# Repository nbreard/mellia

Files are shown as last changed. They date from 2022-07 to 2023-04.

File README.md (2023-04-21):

# MD10 board

Environnement setup : 

Software :

 STM32CubeIDE : for compilation debugging and flashing 
		
 STM32CubeProgrammer: for deactivate write protection bit

Hardware : LoRaWAN gateway connected to LoRaWAN server (TTN)

# MELLIA - Kit Dadant 10

## Présentation

Le kit Mellia Dadant 10 est un ensemble de capteurs connectés permettant d’obtenir des informations essentielles relatives à l’exploitation d’une ruche dans l’objectif de suivre l’évolution de la colonie en réduisant le nombre d’interventions intrusives et les déplacement de l’apiculteur.

Ce kit s’adapte sur une ruche Dadant 10, le modèle le plus utilisé actuellement. Il comprend un dispositif de pesée électronique, un dispositif de mesure de température et humidité intérieure et extérieure, un capteur de pression atmosphérique ainsi qu’un module de communication sans fil. L’ensemble des acquisitions sont enregistrées dans une base de données, un tableau de bord permet le suivi de l’état de la ruche.

## Fonctionnalités

### Mesure poids de la ruche

On pèse la ruche à intervalle régulier pour faire remonter une donnée sur la masse à l’apiculteur. Cela permet d’obtenir un indice de l’état de santé de la colonie et d’envisager d’intervenir ou non sur la ruche (rajout de candi, miellée etc). 

### Température extérieure

Une captation de température dans l’environnement immédiat de la ruche renseigne l’apiculteur sur la météo du milieu dans lequel évolue la colonie d’abeille et donne la capacité d’anticiper une miellée par exemple.

### Température intérieure

La mesure de la température à l’intérieur de la ruche fournis une information sur l’état de santé du couvain. Pour se développer correctement sa température doit rester dans une plage de mesure de 18 à 35°C. Sortir de cette plage indique un danger pour la colonie. Des variations régulières de la température est un signe d’essaimage.

### Humidité extérieure

Utile au rafraîchissement de la ruche ou intervenant directement dans la probabilité de voir se développer des champignons, le taux d’humidité intervient directement dans la vie de la colonie et le mesurer peut se révéler être un élément clé pour comprendre l’activité de la ruche.

### Humidité intérieure

Cette donnée a une incidence sur l’état de santé du couvain, en effet si celui ci est trop humide les parois en deviennent fragiles. Le taux d’humidité est aussi un bon indicateur de la qualité du miel.

### Pression atmosphérique

En corrélation avec l’humidité et la température extérieure, la pression atmosphérique fournit à l’apiculteur une vision globale sur le milieu à proximité de la ruche et sur les éléments auxquels sont soumis les abeilles 

### [Tableau de bord](https://grafana.mellia.lab.open.studio/login "https://grafana.mellia.lab.open.studio/login")

Pour faciliter l’information et la prise de décision les données sont rassemblées dans un tableau de bords consultable en ligne.

## Notice

### Composants du kit

Pour les composants sur la carte se référer au document md10-board/hardware/wheather_board_v1/wheather_board_v1.csv

| composant | référence |
| --- | --- |
| jauge de contrainte | tedea 1242 |
| antenne | MOLEX  105262-0001 |
| boîtier | TAM 131007 ENCLOSURE |
| panneau solaire + batterie | |

### Montage

### Mise en œuvre

## Software 

**Prérequis** : 

Télécharger le logiciel STM32CubeIDE : <https://www.st.com/en/development-tools/stm32cubeide.html>

Télécharger le logiciel STM32CubeProgrammer : <https://www.st.com/en/development-tools/stm32cubeide.html>

Télécharger le code grâce à la commande suivante : 

Git clone <https://gitlab.openstudio-lab.com/mellia/mellia.git>

**Ouvrir le projet :** 

Ouvrir stm32CubeIde, sélectionner ~/md10-board/software/ruche\_soft comme workspace

Depuis STM32CubeIDE, cliquer sur File et « Open Project from file system »



Dans la fenêtre qui s’ouvre cliquer sur directory et sélectionner : ~/md10-board/software/ruche\_soft/STM32Cube\_FW\_WL\_V1.1.0/Projects/NUCLEO-WL55JC/Applications/LoRaWAN/LoRaWAN\_End\_Node/STM32CubeIDE

Les librairies des composants sont accessibles depuis Drivers. Le dossier Sensors contient les fonctions des différentes de mesures, poids, température etc.

Application contient le code de la machine à état qui fait tourner le programme mais aussi les drivers des périphériques de communication tel que le SPi l’i2c ou encore le protocole de communication LoRaWAN servant à faire remonter les données.

L’acquisition des mesures est faite au cours de la fonction SendTxData située dans lora\_app.c

**Flasher le programme :**

Connecter le debugger : 

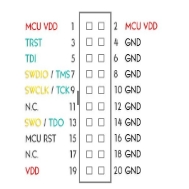
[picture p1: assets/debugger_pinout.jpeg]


Se connecter au microcontrolleur en utilise STM32Cubeprogramme et désactiver la protection en écriture : 

Pour lancer le debugger depuis stmcubeide appliquer cette configuration depuis Run -> debug configuration : 



Attention pour des raisons d’optimisation la sonde de debug et le mode low power est activé. Pour faire plus que flasher le code est debugger en mode pas à pas il faut se rendre dans sys\_conf.h et régler sur 1 les #define suivants : DEBUGGER\_ENABLED et LOW\_POWER\_DISABLE

**Procédure de calibration de la balance** 

On utilise les équations données par TI dans le document relatif à la bonne utilisation de la carte ADS1242 : 



On a besoin de 3 paramètres : 

- wfs  : la masse la plus proche possible de la pleine échelle
- Cfs  : la sortie de l’dc correspondant à wfs
- Czs : la sortie de l’adc lorsque la balance est à vide

À l’aide de ces trois données on peut en déduire l’équation 1 puis la 2 . On place un points d’arrêt dans le code après la mesure pour récupérer cfs et czs.

Les paramètres wzs et m sont à introduire en dur dans le code dans la fonction d’initialisation de l’ads1232 : void ADS1232Sensors\_Init(sensor\_t \*sensor\_data) 

Lors de l'assemblage d'une nouvelle balance, il est important de sélectionner les variables pour une jauge de 100kg ou de 250kg dans la fonction ADS1232Sensors_Init() contenu dans weight_sensor.c

#### Node-red

Node-red est un outil de développement basé sur les flux. Il sert ici à récupérer les données en provenance du broker MQTT fournit par TTN et à les enregistrer dans une base de donnée influxDB. Les ressources pour le déployer se situe dans le répertoir software

Pour se connecter au broker on commence par ajouter le module MQTT à l'interface node red en suivant ce tutoriel : 
https://www.thethingsnetwork.org/forum/t/mqtt-in-node-red-howto/39909

NB : nous utilisons Orange plutôt que TTN pour recevoir les données LoRa mais le principe est le même

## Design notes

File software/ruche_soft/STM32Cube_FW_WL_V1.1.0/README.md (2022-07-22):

# STM32CubeWL MCU Firmware Package



**STM32Cube** is an STMicroelectronics original initiative to ease developers' life by reducing efforts, time and cost.

**STM32Cube** covers the overall STM32 products portfolio. It includes a comprehensive embedded software platform (this repo), delivered for each series (such as the STM32CubeWL for the STM32WL series).
   * The CMSIS modules (core and device) corresponding to the ARM tm core implemented in this STM32 product
   * The STM32 HAL-LL drivers : an abstraction drivers layer, the API ensuring maximized portability across the STM32 portfolio 
   * The BSP Drivers of each evaluation or demonstration board provided by this STM32 series 
   * A consistent set of middlewares libraries such as RTOS, FatFS, LoRaWAN, Sigfox, Key Management Services ...
   * A full set of software projects (basic examples, applications or demonstrations) for each board provided by this STM32 series
   
The **STM32CubeWL MCU Package** projects are directly running on the STM32WL series boards. You can find in each Projects/*Board name* directories a set of software projects (Applications/Demonstration/Examples). 

## Boards available
  * STM32WL 
    * [NUCLEO-WL55JC](https://www.st.com/en/evaluation-tools/nucleo-wl55jc.html)

## Troubleshooting

**Caution** : The **Issues** requests are strictly limited to submit problems or suggestions related to the software delivered in this repo 

**For any question** related to the STM3WL product, the hardware performance, the hardware characteristics, the tools, the environment, you can submit a topic on the [ST Community/STM32 MCUs forum](https://community.st.com/s/group/0F90X000000AXsASAW/stm32-mcus)

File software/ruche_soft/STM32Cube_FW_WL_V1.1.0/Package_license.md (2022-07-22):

---
pagetitle: Package License Terms for <package RPN name>
lang: en
header-includes: <link rel="icon" type="image/x-icon" href="_htmresc/favicon.png" />
---

::: {.row}
::: {.col-sm-12 .col-lg-3}

<center>
# These are full license terms for

# <mark>STM32CubeWL</mark>

Copyright &copy; 2021 STMicroelectronics

All rights reserved
    
ST logo (https://www.st.com)
{.logo}
</center>
:::

::: {.col-sm-12 .col-lg-9}
::: {.collapse}
<input type="checkbox" id="collapse-section1" checked aria-hidden="true">
<label for="collapse-section1" aria-hidden="true">__SLA0048__</label>
<div>

SLA0048 Rev4/March 2018

## Software license agreement

### __SOFTWARE PACKAGE LICENSE AGREEMENT__

BY INSTALLING COPYING, DOWNLOADING, ACCESSING OR OTHERWISE USING THIS SOFTWARE PACKAGE OR ANY
PART THEREOF (AND THE RELATED DOCUMENTATION) FROM STMICROELECTRONICS INTERNATIONAL N.V, SWISS
BRANCH AND/OR ITS AFFILIATED COMPANIES (STMICROELECTRONICS), THE RECIPIENT, ON BEHALF OF HIMSELF
OR HERSELF, OR ON BEHALF OF ANY ENTITY BY WHICH SUCH RECIPIENT IS EMPLOYED AND/OR ENGAGED
AGREES TO BE BOUND BY THIS SOFTWARE PACKAGE LICENSE AGREEMENT.

Under STMicroelectronics’ intellectual property rights and subject to applicable licensing terms for any third-party software
incorporated in this software package and applicable Open Source Terms (as defined here below), the redistribution,
reproduction and use in source and binary forms of the software package or any part thereof, with or without modification, are
permitted provided that the following conditions are met:

1. Redistribution of source code (modified or not) must retain any copyright notice, this list of conditions and the following
disclaimer.

2. Redistributions in binary form, except as embedded into microcontroller or microprocessor device manufactured by or for
STMicroelectronics or a software update for such device, must reproduce the above copyright notice, this list of conditions
and the following disclaimer in the documentation and/or other materials provided with the distribution.

3. Neither the name of STMicroelectronics nor the names of other contributors to this software package may be used to
endorse or promote products derived from this software package or part thereof without specific written permission.

4. This software package or any part thereof, including modifications and/or derivative works of this software package, must
be used and execute solely and exclusively on or in combination with a microcontroller or a microprocessor devices
manufactured by or for STMicroelectronics.

5. No use, reproduction or redistribution of this software package partially or totally may be done in any manner that would
subject this software package to any Open Source Terms (as defined below).

6. Some portion of the software package may contain software subject to Open Source Terms (as defined below) applicable
for each such portion (“Open Source Software”), as further specified in the software package. Such Open Source Software
is supplied under the applicable Open Source Terms and is not subject to the terms and conditions of license hereunder.
“Open Source Terms” shall mean any open source license which requires as part of distribution of software that the source
code of such software is distributed therewith or otherwise made available, or open source license that substantially
complies with the Open Source definition specified at www.opensource.org and any other comparable open source license
such as for example GNU General Public License (GPL), Eclipse Public License (EPL), Apache Software License, BSD
license and MIT license.

7. This software package may also include third party software as expressly specified in the software package subject to
specific license terms from such third parties. Such third party software is supplied under such specific license terms and is
not subject to the terms and conditions of license hereunder. By installing copying, downloading, accessing or otherwise
using this software package, the recipient agrees to be bound by such license terms with regard to such third party
software.

8. STMicroelectronics has no obligation to provide any maintenance, support or updates for the software package.

9. The software package is and will remain the exclusive property of STMicroelectronics and its licensors. The recipient will
not take any action that jeopardizes STMicroelectronics and its licensors' proprietary rights or acquire any rights in the
software package, except the limited rights specified hereunder.

10. The recipient shall comply with all applicable laws and regulations affecting the use of the software package or any part
thereof including any applicable export control law or regulation.

11. Redistribution and use of this software package partially or any part thereof other than as permitted under this license is
void and will automatically terminate your rights under this license.

THIS SOFTWARE PACKAGE IS PROVIDED BY STMICROELECTRONICS AND CONTRIBUTORS "AS IS" AND ANY
EXPRESS, IMPLIED OR STATUTORY WARRANTIES, INCLUDING, BUT NOT LIMITED TO, THE IMPLIED WARRANTIES OF
MERCHANTABILITY, FITNESS FOR A PARTICULAR PURPOSE AND NON-INFRINGEMENT OF THIRD PARTY
INTELLECTUAL PROPERTY RIGHTS ARE DISCLAIMED TO THE FULLEST EXTENT PERMITTED BY LAW. IN NO EVENT
SHALL STMICROELECTRONICS OR CONTRIBUTORS BE LIABLE FOR ANY DIRECT, INDIRECT, INCIDENTAL, SPECIAL,
EXEMPLARY, OR CONSEQUENTIAL DAMAGES (INCLUDING, BUT NOT LIMITED TO, PROCUREMENT OF SUBSTITUTE
GOODS OR SERVICES; LOSS OF USE, DATA, OR PROFITS; OR BUSINESS INTERRUPTION) HOWEVER CAUSED AND
ON ANY THEORY OF LIABILITY, WHETHER IN CONTRACT, STRICT LIABILITY, OR TORT (INCLUDING NEGLIGENCE OR
OTHERWISE) ARISING IN ANY WAY OUT OF THE USE OF THIS SOFTWARE PACKAGE, EVEN IF ADVISED OF THE
POSSIBILITY OF SUCH DAMAGE.

EXCEPT AS EXPRESSLY PERMITTED HEREUNDER AND SUBJECT TO THE APPLICABLE LICENSING TERMS FOR ANY
THIRD-PARTY SOFTWARE INCORPORATED IN THE SOFTWARE PACKAGE AND OPEN SOURCE TERMS AS
APPLICABLE, NO LICENSE OR OTHER RIGHTS, WHETHER EXPRESS OR IMPLIED, ARE GRANTED UNDER ANY
PATENT OR OTHER INTELLECTUAL PROPERTY RIGHTS OF STMICROELECTRONICS OR ANY THIRD PARTY.

</div>
:::

::: {.collapse}
<input type="checkbox" id="collapse-section2" checked aria-hidden="true">
<label for="collapse-section2" aria-hidden="true">__ANNEX 1: LIST OF SOFTWARE COMPONENTS (AND ASSOCIATED LICENSES) IN THE SOFTWARE PACKAGE__</label>
<div>
Component                       Copyright                           License
---------                       ---------                           -------
CMSIS                           ARM Limited                         [Apache-2.0](https://opensource.org/licenses/Apache-2.0)
CMSIS Device                    ARM Limited - STMicroelectronics    [Apache-2.0](https://opensource.org/licenses/Apache-2.0)
STM32WL HAL                     STMicroelectronics                  [BSD-3-Clause](https://opensource.org/licenses/BSD-3-Clause)
BSP NUCLEO-WL55JC               STMicroelectronics                  [BSD-3-Clause](https://opensource.org/licenses/BSD-3-Clause)
FreeRTOS kernel                 Amazon.com, Inc. or its affiliates  [MIT](https://opensource.org/licenses/MIT) 
FatFS                           ChaN - STMicroelectronics           [BSD-3-Clause](https://opensource.org/licenses/BSD-3-Clause)
SubGHz_Phy                      Semtech - STMicroelectronics        [BSD-3-Clause](https://opensource.org/licenses/BSD-3-Clause)
LoRaWAN                         Semtech - STMicroelectronics        [BSD-3-Clause](https://opensource.org/licenses/BSD-3-Clause)
Sigfox                          Sigfox - STMicroelectronics         Proprietary and See ANNEX 2
mbed-crypto                     ARM Limited (or its affiliates)     [Apache-2.0](https://opensource.org/licenses/Apache-2.0)
STM32_Key_Management_Services   STMicroelectronics                  Proprietary
STM32_Secure_Engine             STMicroelectronics                  Proprietary
STM32 Projects                  STMicroelectronics                  Proprietary ([BSD-3-Clause](https://opensource.org/licenses/BSD-3-Clause) for basic Examples)
STM32 Utilities                 STMicroelectronics                  [BSD-3-Clause](https://opensource.org/licenses/BSD-3-Clause)

</div>
:::

::: {.collapse}
<input type="checkbox" id="collapse-section3" checked aria-hidden="true">
<label for="collapse-section3" aria-hidden="true">__ANNEX 2: SIGFOX Specific Terms__</label>
<div>

By downloading, or attempting to download, the SIGFOX protocol library "SFX_LIB_V2.10.0_SE_FDL_MON.a" and/or 
"SFX_ADDON_RFP_V0.8.0_SE_FDL_MON_ASYNC.a" , you are hereby informed and you acknowledge and agree that any use of 
the licensed materials is subject to all terms and conditions required by SIGFOX and listed below:
• You shall 
  o respect the Partner Certification Process, described in the SIGFOX developer platform at  
    http://build.SIGFOX.com to embed applicable authentication keys; 
  o be in compliance with all applicable laws, regulations (including any applicable 
    export control law or regulation) and industry standards in connection with the manufacture, sale 
    and/or distribution of certified products;
• You shall not:
 o modify or create without SIGFOX written prior agreement any derivative work of any part of the 
   SIGFOX protocol library 
 o market, sell, license, distribute, publish, display, reproduce, rent, lease, loan, assign or otherwise 
   transfer to a third party the SIGFOX protocol library or any copy thereof, in whole or in part; 
 o install or otherwise incorporate the SIGFOX protocol library into a product except as set 
   forth in and in accordance with this document; 
 o use the SIGFOX protocol library in any way that would not be in compliance with applicable laws; 
 o except to the extent permitted by law, permit the disassembly, decompilation or reverse engineering
   of the SIGFOX protocol library or otherwise attempt to gain access to the source code to the SIGFOX 
   protocol library (or the underlying ideas, algorithms, structure or organization of the object code 
   in the SIGFOX protocol library)
 o incorporate any open source software into any product, including with respect to certified products 
   sold or distributed, that creates or purports to create any obligation to disclose to a third party 
   any source code relating to the SIGFOX protocol library or grants or purports to grant to any third 
   party any intellectual property of SIGFOX; 
 o develop, sell or distribute any product that undermines SIGFOX network security and integrity and/or 
   introduces in any SIGFOX network any viruses, worms, Trojan horses or similar harmful or malicious 
   code, or otherwise harms any SIGFOX network; 
 o remove or attempt to remove any SIGFOX authentication keys,
 o incorporate the SIGFOX protocol library in any product for connection on another network than SIGFOX 
   network. You shall inform any of your third party that such infringement to the obligations below 
   would cause significant harm to SIGFOX.

You shall have no rights to any source code for the SIGFOX protocol library. You agree that only SIGFOX 
shall have the right to maintain, enhance or otherwise modify the SIGFOX protocol library. 

</div>
:::

:::
:::

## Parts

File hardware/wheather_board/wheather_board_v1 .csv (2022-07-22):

Id | Designator | Package | Quantity | Designation | tol���rance | tension nominale | ref fabricant
1 | C7,C3 | C_0805_2012Metric_Pad1.18x1.45mm_HandSolder | 2 | 2.2uF | 10.00% | 25V | 08053C225KAT2A
2 | ,REF**,REF**, | MountingHole_3.7mm_Pad_Via | 4 | MountingHole_3.7mm_Pad_Via | x | x | x
3 | J2 | PinSocket_1x02_P2.54mm_Vertical | 1 | Conn_01x02_Male | x | x | 826629-2
4 | J1 | PinSocket_1x02_P2.54mm_Vertical | 1 | Conn_01x02_Female | x | x | 282834-2
5 | SW1 | SW_SPST_PTS645 | 1 | SW_MEC_5G | x |  | KSEK43J LFS
6 | C25 | CP_EIA-7343-31_Kemet-D_Pad2.25x2.55mm_HandSolder | 1 | 100uF | 20.00% | 10V | T491D107M010AT
7 | C22 | Capacitor_Tantalum_SMD:CP_EIA-3216-18_Kemet-A | 1 | 0.1uF | 10.00% | 35V | T491A104K035AT
8 | R14 | R_0805_2012Metric_Pad1.20x1.40mm_HandSolder | 1 | 10k | 0.10% | 50V | ERA6AEB103V
9 | U4 | LD39050PUR | 1 | LD39050PU33R | 2.00% | 3.3V | LD39050PU33R
10 | U5 | SOIC-8_3.9x4.9mm_P1.27mm | 1 | REF5050AD | 20ppm | 5V | REF5050AID
11 | U2 | Bosch_LGA-8_3x3mm_P0.8mm_ClockwisePinNumbering | 1 | BME680 | x
12 | U1 | SOT-223-3_TabPin2 | 1 | LD1117S50TR_SOT223 | 2.00%
13 | R13 | R_0805_2012Metric_Pad1.20x1.40mm_HandSolder | 1 | DNP | x | x | x
14 | R10,R9 | R_0805_2012Metric_Pad1.20x1.40mm_HandSolder | 3 | 0 | 5.00% | 150V
15 | R12,R11 | R_0805_2012Metric_Pad1.20x1.40mm_HandSolder | 2 | 100 | 0.10% | 150V | MCTC0525B1000T5G
16 | R8 | R_0805_2012Metric_Pad1.20x1.40mm_HandSolder | 1 | 1 | 1.00% | 150V | RC0805FR-071RL
17 | R7,R6,R5 | R_0805_2012Metric_Pad1.20x1.40mm_HandSolder | 3 | 22 | 1.00% | 150V | MCWR08X22R0FTL
18 | R4,R3,R2,R1 | R_0805_2012Metric_Pad1.20x1.40mm_HandSolder | 4 | 22 | 1.00% | 150V | MCWR08X22R0FTL
19 | L1 | L_0805_2012Metric_Pad1.15x1.40mm_HandSolder | 1 | dnp | x | x | x
20 | J9 | U.FL_Hirose_U.FL-R-SMT-1_Vertical | 1 | Conn_Coaxial | x |  | U.FL-R-SMT(01)
21 | J8 | PinHeader_1x04_P2.54mm_Vertical | 1 | Conn_01x04_Male | x |  | 282834-4
22 | J7 | PinHeader_1x06_P2.54mm_Vertical | 1 | Conn_01x06_Female | x |  | 1725698
23 | J6,J10 | PinHeader_1x05_P2.54mm_Vertical | 2 | Conn_01x05_Female | x |  | 282834-5
24 | D1 | D_SMB-SMC_Universal_Handsoldering | 1 | D | x |  | MRS1504T3G
25 | C29,C27 | C_0805_2012Metric_Pad1.18x1.45mm_HandSolder | 2 | dnp | x
26 | C28,C11,C9,C6,C4 | C_0805_2012Metric_Pad1.18x1.45mm_HandSolder | 5 | 100nF | 20.00% | 50V
27 | C26 | C_0805_2012Metric_Pad1.18x1.45mm_HandSolder | 1 | 4.7uF | -400 | 16V | C0805C475J4RACAUTO
28 | C24,C21,C10,C8 | C_0805_2012Metric_Pad1.18x1.45mm_HandSolder | 4 | 1uF | 10.00% | 16V | MC0805B105K160CT
29 | C23 | C_0805_2012Metric_Pad1.18x1.45mm_HandSolder | 1 | 1uF | 10.00% | 16V | MC0805B105K160CT
30 | C20,C19,C18,C17 | NFM21PC105B1C3D | 4 | C_Feedthrough | 20.00% | 16V | NFM21PC105B1C3D
31 | C16,C15,C13,C12 | C_0805_2012Metric_Pad1.18x1.45mm_HandSolder | 4 | 100pF | 5.00% | 50V | CC0805JRNPO9BN101
32 | C14 | C_0805_2012Metric_Pad1.18x1.45mm_HandSolder | 1 | 10uF | 20.00% | 10V | C0805X106M8RACTU
33 | C5 | CP_EIA-3216-18_Kemet-A_Pad1.58x1.35mm_HandSolder | 1 | 10uF | 10.00% | 16V | T491A106K016AT
34 | C2 | C_1210_3225Metric_Pad1.33x2.70mm_HandSolder | 1 | 0.1uF | 10.00% | 50V
35 | C1 | CP_EIA-3528-21_Kemet-B_Pad1.50x2.35mm_HandSolder | 1 | 10uF | 10.00% | 10V | T494B106M010AT
36 | J5 | PinHeader_1x06_P2.54mm_Vertical | 1 | Conn_01x06_Male | x |  | 9731113
37 | J4 | PinHeader_1x03_P2.54mm_Vertical | 1 | Conn_01x03_Male | x |  | 9731083
38 | U3 | ADS1232IPW | 1 | PW0024A_N | x |  | ADS1232IPW
39 | U6 | LoRa-E5 | 1 | LoRa-E5 | x |  | 317990687
40 |  | CRE1S0505SC | 1 | CRE1S0505SC | x |  | CRE1S0505SC
41 | G*** | logo_mellia | 1 | MELLIA | x |  | x

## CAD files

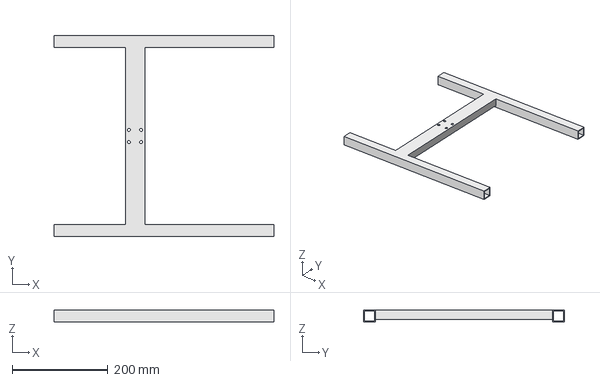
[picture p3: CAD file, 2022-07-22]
mechanic/weight_scale_frame.FCStd
460.0 x 420.0 x 25.0 mm

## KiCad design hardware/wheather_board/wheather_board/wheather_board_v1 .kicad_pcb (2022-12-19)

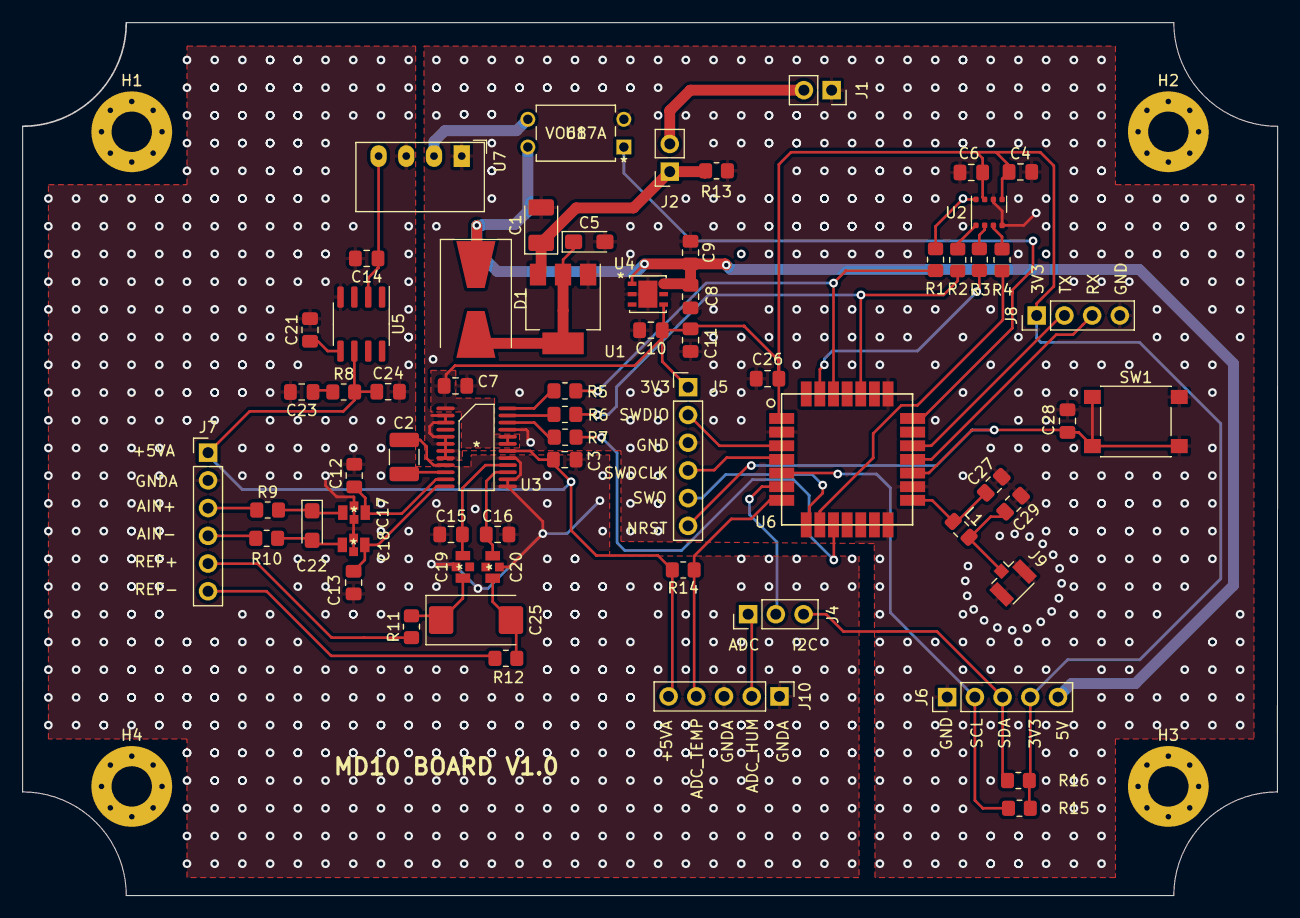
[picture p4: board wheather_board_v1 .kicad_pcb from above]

Board: 2 copper layers, 115.0 x 80.0 mm, 69 parts (0 on the bottom side), 53 nets.

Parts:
C1: 10uF; CP_EIA-3528-21_Kemet-B_Pad1.50x2.35mm_HandSolder
C2: 0.1uF; C_1210_3225Metric_Pad1.33x2.70mm_HandSolder
C3, C7: 2.2uF; C_0805_2012Metric_Pad1.18x1.45mm_HandSolder
C4, C6, C9, C11, C28: 100nF; C_0805_2012Metric_Pad1.18x1.45mm_HandSolder
C5: 10uF; CP_EIA-3216-18_Kemet-A_Pad1.58x1.35mm_HandSolder
C8, C10, C21, C24: 1uF; C_0805_2012Metric_Pad1.18x1.45mm_HandSolder
C12, C13, C15, C16: 100pF; C_0805_2012Metric_Pad1.18x1.45mm_HandSolder
C14: 1uF to 10 uF; C_0805_2012Metric_Pad1.18x1.45mm_HandSolder
C17, C18, C19, C20: C_Feedthrough; NFM21PC105B1C3D
C22: 0.1uF; CP_EIA-3216-18_Kemet-A
C23: 1uF to 50uF; C_0805_2012Metric_Pad1.18x1.45mm_HandSolder
C25: 100uF; CP_EIA-7343-31_Kemet-D_Pad2.25x2.55mm_HandSolder
C26: 4.7uF; C_0805_2012Metric_Pad1.18x1.45mm_HandSolder
C27, C29: dnp; C_0805_2012Metric_Pad1.18x1.45mm_HandSolder
D1: D; D_SMB-SMC_Universal_Handsoldering
H1, H2, H3, H4: MountingHole; MountingHole_3.7mm_Pad_Via
J1: Conn_01x02_Female; PinSocket_1x02_P2.54mm_Vertical
J2: Conn_01x02_Male; PinSocket_1x02_P2.54mm_Vertical
J4: Conn_01x03_Male; PinHeader_1x03_P2.54mm_Vertical
J5: Conn_01x06_Male; PinHeader_1x06_P2.54mm_Vertical
J6, J10: Conn_01x05_Female; PinHeader_1x05_P2.54mm_Vertical
J7: Conn_01x06_Female; PinHeader_1x06_P2.54mm_Vertical
J8: Conn_01x04_Male; PinHeader_1x04_P2.54mm_Vertical
J9: Conn_Coaxial; U.FL_Hirose_U.FL-R-SMT-1_Vertical
L1: dnp; L_0805_2012Metric_Pad1.15x1.40mm_HandSolder
R1, R2, R3, R4, R15, R16: R; R_0805_2012Metric_Pad1.20x1.40mm_HandSolder
R5, R6, R7: 22; R_0805_2012Metric_Pad1.20x1.40mm_HandSolder
R8: 1; R_0805_2012Metric_Pad1.20x1.40mm_HandSolder
R9, R10, R13: 0; R_0805_2012Metric_Pad1.20x1.40mm_HandSolder
R11, R12: 100; R_0805_2012Metric_Pad1.20x1.40mm_HandSolder
R14: 10k; R_0805_2012Metric_Pad1.20x1.40mm_HandSolder
SW1: SW_MEC_5G; SW_SPST_PTS645
U1: LD1117S50TR_SOT223; SOT-223-3_TabPin2
U2: BME680; Bosch_LGA-8_3x3mm_P0.8mm_ClockwisePinNumbering
U3: ADS1232IPW
U4: LD39050PUR
U5: REF5050AD; SOIC-8_3.9x4.9mm_P1.27mm
U6: LoRa-E5
U7: CRE1S0505SC; Converter_DCDC_muRata_CRE1xxxxxxSC_THT
U8: VO617A

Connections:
+3.3V: J6.4, R15.2, R16.2
+3V3: C4.1, C6.1, C7.2, C10.1, C11.1, C26.1, J5.1, J8.1, U2.6 (VDDIO), U2.8 (VDD), U3.1 (DVDD), U3.19 (GAIN0), U3.20 (GAIN1), U4.4 (VOUT), U6.1 (VCC)
+5V: C8.2, C9.2, D1.1 (K), J6.5, U4.1 (EN), U4.6 (VIN), U8.4 (C)
+5VA: C3.1, C24.1, J7.1, J10.5, R8.2, R14.2, U3.18 (AVDD), U5.6 (Vout)
/ADC_HUM: J4.1, J10.2
/ADC_TEMP: J10.4, R14.1, U6.7 (PB4)
/ADS_NSS: R7.1, U6.10 (PB6)
/AIN+: J7.3, R9.1
/AIN-: J7.4, R10.1
/AINN1: C13.1, C18.3, U3.12 (AINN1)
/AINP1: C12.2, C17.1, U3.11 (AINP1)
/BME_NSS: R4.1, U6.9 (PB7)
/EN_VDDA: U6.21 (PA9), U8.1 (A)
/I2C_SCL: J6.2, R15.1, U6.5 (PB15)
/I2C_SDA: J4.3, J6.3, R16.1
/NRST: C28.2, J5.6, SW1.1 (A), SW1.2 (A), U6.17 (RST)
/REFN: C16.1, C20.3, U3.15 (REFN)
/REFP: C15.2, C19.1, U3.16 (REFP)
/SPI_MISO: R1.1, R5.1, U6.26 (PB14)
/SPI_MOSI: R3.1, U6.27 (PA10)
/SPI_SCK: R2.1, R6.1, U6.24 (PB13~)
/SWDCLK: J5.4, U6.4 (PA14)
/SWDIO: J5.2, U6.3 (PA13)
/SWO: J5.5, U6.8 (PB3)
/UART_RX: J8.3, U6.18 (PA3)
/UART_TX: J8.2, U6.19 (PA2)
/ref+: J7.5, R11.1
/ref-: J7.6, R12.1
/toref: C14.1, U5.2 (Vin), U7.4 (+VOUT)
GND: C1.2, C4.2, C5.2, C6.2, C7.1, C8.1, C9.1, C10.2, C11.2, C26.2, C27.2, C28.1, C29.2, J1.1, J5.3, J6.1, J8.4, J9.2 (Ext), R13.1, SW1.1 (A), SW1.2 (A), U1.1 (GND), U2.1 (GND), U2.7 (GND), U3.2 (DGND), U3.3 (CLKIN/XTAL1), U3.5 (DGND), U3.6 (DGND), U3.7 (TEMP), U3.8 (A0), U3.21 (SPEED), U4.2 (GND), U4.7 (GND), U6.2 (GND), U6.14 (GND), U6.16 (GND), U6.22 (GND), U7.1 (-VIN), U8.2 (C)
GNDA: C3.2, C12.1, C13.2, C14.2, C15.1, C16.2, C17.2, C18.2, C19.2, C20.2, C21.2, C23.2, C24.2, J7.2, J10.1, J10.3, U3.13 (AINN2), U3.14 (AINP2), U3.17 (AGND), U5.4 (GND), U7.3 (-VOUT)
unnamed: C1.1, J2.1, R13.2, U1.3 (VI)
unnamed: C2.1, U3.9 (CAP)
unnamed: C2.2, U3.10 (CAP)
unnamed: C5.1, D1.2 (A), U1.2 (VO)
unnamed: C17.3, C22.1, R9.2
unnamed: C18.1, C22.2, R10.2
unnamed: C19.3, C25.1, R11.2
unnamed: C20.1, C25.2, R12.2
unnamed: C21.1, U5.5 (Trim/NR)
unnamed: C23.1, R8.1
unnamed: C27.1, L1.1, U6.15 (RFIO)
unnamed: C29.1, J9.1 (In), L1.2
unnamed: J4.2, U6.6 (PA15)
unnamed: R1.2, U2.5 (SDO)
unnamed: R2.2, U2.4 (SCK)
unnamed: R3.2, U2.3 (SDI)
unnamed: R4.2, U2.2 (CSB)
unnamed: R5.2, U3.24 (~DRDY/DOUT)
unnamed: R6.2, U3.23 (SCLK)
unnamed: R7.2, U3.22 (~PWDN)
unnamed: U7.2 (+VIN), U8.3 (E)
VCC: J1.2, J2.2

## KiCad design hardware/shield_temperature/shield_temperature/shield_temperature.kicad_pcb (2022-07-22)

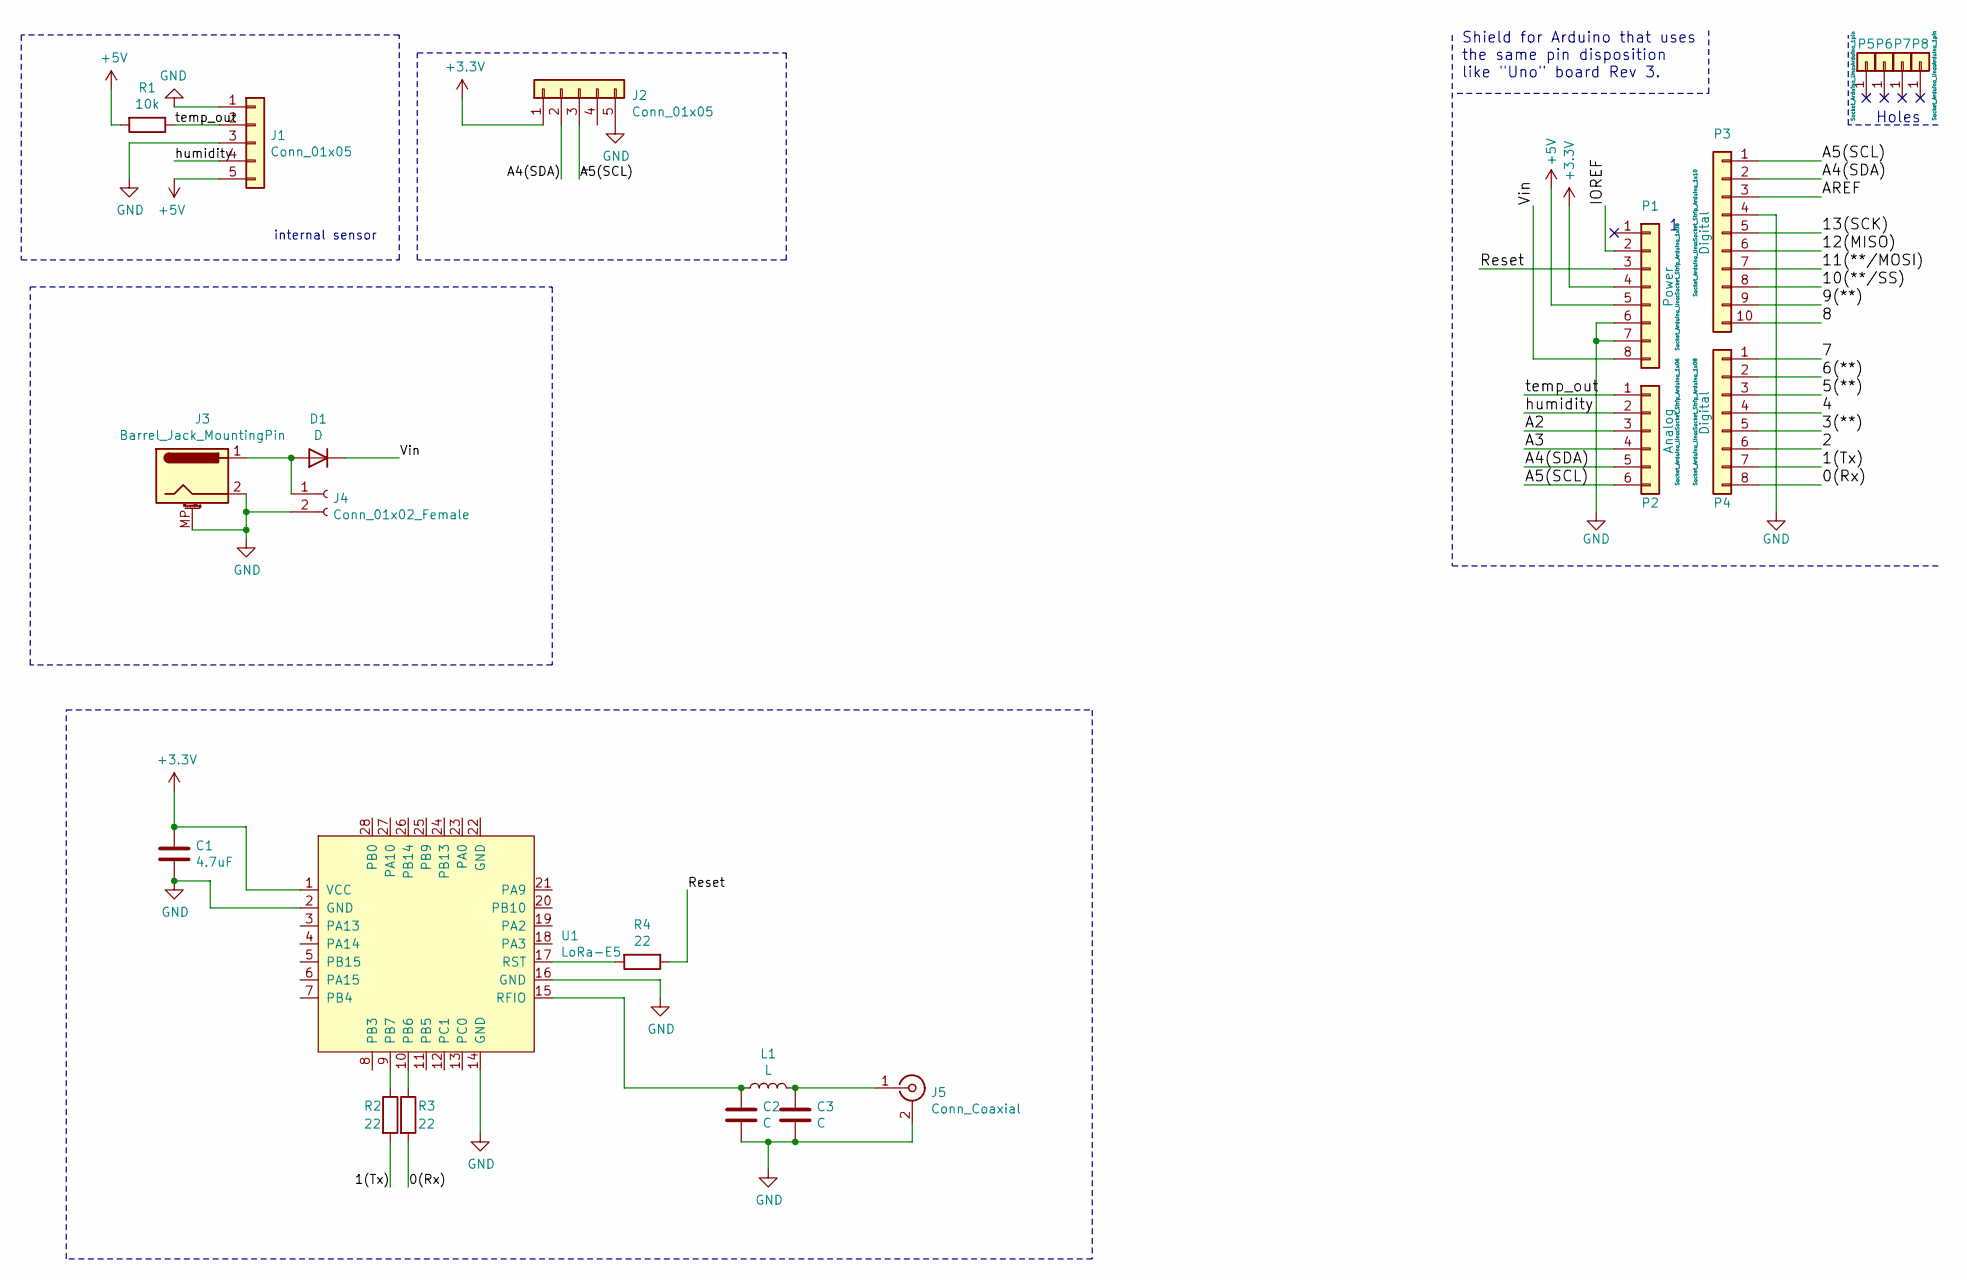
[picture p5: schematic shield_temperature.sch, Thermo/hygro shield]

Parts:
C1: 4.7uF; C_0805_2012Metric
C2, C3: C; C_0805_2012Metric
D1: D; D_SMB
J1: Conn_01x05; D_SMB
J2: Conn_01x05; PinHeader_1x05_P2.54mm_Vertical
J3: Barrel_Jack_MountingPin; BarrelJack_Horizontal
J4: Conn_01x02_Female; PinHeader_1x02_P2.54mm_Vertical
J5: Conn_Coaxial; U.FL_Hirose_U.FL-R-SMT-1_Vertical
L1: L; L_0805_2012Metric_Pad1.05x1.20mm_HandSolder
P1: Power; Socket_Strip_Arduino_1x08
P2: Analog; Socket_Strip_Arduino_1x06
P3: Digital; Socket_Strip_Arduino_1x10
P4: Digital; Socket_Strip_Arduino_1x08
P5, P6, P7, P8: CONN_01X01; Arduino_1pin
R1: 10k; R_1206_3216Metric
R2, R3, R4: 22; R_0805_2012Metric
U1: LoRa-E5

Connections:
+3V3: C1.1, J2.1, P1.4, U1.1 (VCC)
+5V: J1.5, P1.5, R1.2
/0(Rx): P4.8, R3.2
/1(Tx): P4.7, R2.2
/2: P4.6
/3(**): P4.5
/4: P4.4
/5(**): P4.3
/6(**): P4.2
/7: P4.1
/8: P3.10
/9(**): P3.9
/10(**/SS): P3.8
/11(**/MOSI): P3.7
/12(MISO): P3.6
/13(SCK): P3.5
/A2: P2.3
/A3: P2.4
/A4(SDA): J2.2, P2.5, P3.2
/A5(SCL): J2.3, P2.6, P3.1
/AREF: P3.3
/IOREF: P1.2
/Reset: P1.3, R4.1
/Vin: D1.1 (K), P1.8
/humidity: J1.4, P2.2
/temp_out: J1.2, P2.1, R1.1
GND: C1.2, C2.2, C3.2, J1.1, J1.3, J2.5, J3.2, J3.MP (MountPin), J4.2, J5.2 (Ext), P1.6, P1.7, P3.4, U1.2 (GND), U1.14 (GND), U1.16 (GND)
unnamed: C2.1, L1.1, U1.15 (RFIO)
unnamed: C3.1, J5.1 (In), L1.2
unnamed: D1.2 (A), J3.1, J4.1
unnamed: R2.1, U1.9 (PB7)
unnamed: R3.1, U1.10 (PB6)
unnamed: R4.2, U1.17 (RST)

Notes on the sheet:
Holes
Shield for Arduino that uses the same pin disposition like "Uno" board Rev 3.
internal sensor

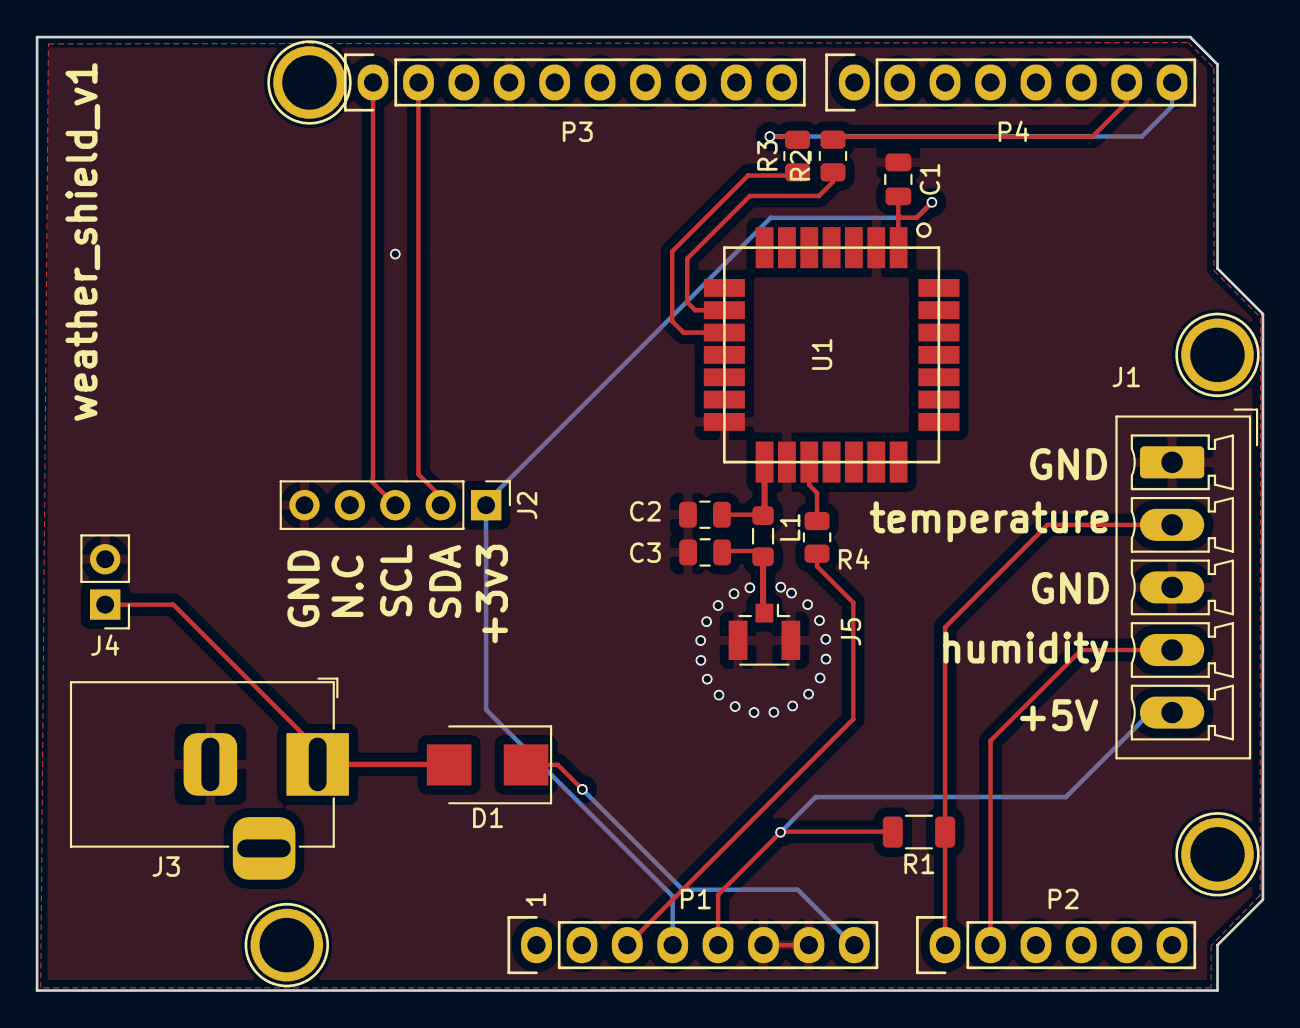
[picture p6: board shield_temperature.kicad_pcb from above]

Board: 2 copper layers, 68.6 x 53.3 mm, 23 parts (0 on the bottom side), 17 nets.

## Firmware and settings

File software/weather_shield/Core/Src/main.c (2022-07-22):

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
/* Includes ------------------------------------------------------------------*/
#include "main.h"

/* USER CODE BEGIN Includes */
#include "stdio.h"
#include "string.h"
#include "uart_if.h"
#include "lora_app.h"
#include "rtc_if.h"
#include "flash.h"
#include "ringbuffer.h"
#include "sys_sensors.h"
/* USER CODE END Includes */

ADC_HandleTypeDef hadc1;

I2C_HandleTypeDef hi2c1;

RTC_HandleTypeDef hrtc;

UART_HandleTypeDef huart5;
UART_HandleTypeDef huart2;

void SystemClock_Config(void);
static void MX_GPIO_Init(void);
static void MX_USART2_UART_Init(void);
void MX_ADC1_Init(void);
void MX_I2C1_Init(void);
static void MX_RTC_Init(void);
static void MX_UART5_Init(void);
/* USER CODE BEGIN 0 */
uint8_t rcvbuff[64]={0};
uint8_t command[64]={0};
uint8_t rcvptr=0;
/* USER CODE END 0 */

/**
 * @brief  The application entry point.
 * @retval int
 */
int main(void)
{
	/* MCU Configuration--------------------------------------------------------*/

	/* Reset of all peripherals, Initializes the Flash interface and the Systick. */
	HAL_Init();

	/* Configure the system clock */
	SystemClock_Config();

	/* Initialize all configured peripherals */
	MX_GPIO_Init();
	MX_USART2_UART_Init();
	MX_ADC1_Init();
	MX_I2C1_Init();
	MX_RTC_Init();
	MX_UART5_Init();
	/* USER CODE BEGIN 2 */
	buffer_init(&queue, adressList,3, BASEADRESSFLASH);
	for(int i=125;i<=127;i++)
		memory_erasePage(i);
	printf("start\r\n");
	printf("LoRa init\r\n");
		LoRa_init();


		//setDate(&huart2 ,&hrtc);
	/*	uint8_t rcvbuff[64]={0};
	sensor_t sensor_data;

	HAL_UART_Transmit(&huart5,(uint8_t *) "P3\r", 3, 10);
	HAL_UART_Receive(&huart5,rcvbuff, 59, 1100);
	HAL_UART_Transmit(&huart5,(uint8_t *) "K\r", 2, 10);
	HAL_UART_Receive(&huart5,rcvbuff, 59, 1100);
	sensor_data.scale.wfs=6;
	sensor_data.scale.wt=0;
	ADS1232Read(&huart5,&sensor_data); // mesure à vide
	sensor_data.scale.czs=sensor_data.scale.c;
	ADS1232Read(&huart5,&sensor_data); // mesure en charge
	sensor_data.scale.cfs=sensor_data.scale.c;

	sensor_data.scale.m=(float)sensor_data.scale.wfs/(float)(sensor_data.scale.cfs-sensor_data.scale.czs);
	sensor_data.scale.wzs=-sensor_data.scale.m*(float)sensor_data.scale.czs;
	return 0;*/
	/* USER CODE END 2 */
	/* Infinite loop */
	/* USER CODE BEGIN WHILE */
	while (1)
	{
		/* USER CODE END WHILE */

		/* USER CODE BEGIN 3 */

		//ADS1232Power(&huart5,SET);


		//		 creation du payload
		printf("measurement\r\n");
		CayenneMakeBuffer();
		//	enregistrement du payload

	//	ADS1232Power(&huart5,RESET );

		// envoi du payload
		printf("LoRa processing\r\n");
		if(!LoRa_process())
		{
/*
			if(!setDate(&huart2 ,&hrtc))
			{

				printf("date set \r\n");
			}
			else
			{
				printf("invalid date : configuration aborted \r\n");
			}*/


		}
		printf("et maintenant au dodo \r\n");
		//HAL_ADCEx_EnterADCDeepPowerDownMode(&hadc1);
		//	stopWithAlarm(&hrtc,&sAlarm);


		HAL_SuspendTick();
		HAL_PWR_EnterSTOPMode(PWR_MAINREGULATOR_ON,PWR_SLEEPENTRY_WFI);
		HAL_ResumeTick();
		SystemClock_Config();

	    hadc1.State    = HAL_ADC_STATE_RESET;
		MX_ADC1_Init();
		HAL_ADCEx_Calibration_Start(&hadc1,ADC_SINGLE_ENDED);



	}
	/* USER CODE END 3 */
}

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
/* USER CODE BEGIN 4 */
int __io_putchar(int ch)
{
	ITM_SendChar(ch);
	return(ch);
}

int  _write(int file, char *ptr, int len)
{
	int DataIdx;
	for (DataIdx = 0; DataIdx < len; DataIdx++)
	{
		__io_putchar(*ptr++);
	}
	return   len;
}

void HAL_RTCEx_WakeUpTimerEventCallback(RTC_HandleTypeDef *hrtc)
{
	printf("wake up coucou lalala \r\n");
}


void HAL_UART_RxCpltCallback(UART_HandleTypeDef *huart)
{
	if(huart->Instance==UART5)
	{
		if(rcvbuff[rcvptr]=='\r')
		{
			memcpy(&command[0],&rcvbuff[1],rcvptr-1);
			memset(rcvbuff,0,64);
			rcvptr=0;
		}
		else
		{
			rcvptr++;
		}
		HAL_UART_Receive_IT(&huart5,&rcvbuff[rcvptr],1);
	}
}
/* USER CODE END 4 */
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


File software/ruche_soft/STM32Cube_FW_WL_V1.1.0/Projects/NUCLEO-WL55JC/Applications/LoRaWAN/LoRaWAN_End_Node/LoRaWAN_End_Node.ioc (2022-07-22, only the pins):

Mcu.UserName=STM32WL55JCIx
PA0.GPIO_Label=BUT1
PA0.Signal=GPXTI0
PA1.GPIO_Label=BUT2
PA1.Signal=GPXTI1
PA13.Signal=DEBUG_JTMS-SWDIO
PA14.Signal=DEBUG_JTCK-SWCLK
PA2.GPIO_Label=USARTx_TX
PA2.Signal=USART2_TX
PA3.GPIO_Label=USARTx_RX
PA3.Signal=USART2_RX
PB0-VDD_TCXO.Signal=VDDTCXO
PB10.GPIO_Label=PROB4
PB10.Signal=GPIO_Output
PB11.GPIO_Label=LED3
PB11.Signal=GPIO_Output
PB12.GPIO_Label=PROB1
PB12.Signal=GPIO_Output
PB13.GPIO_Label=PROB2
PB13.Signal=GPIO_Output
PB14.GPIO_Label=PROB3
PB14.Signal=GPIO_Output
PB15.GPIO_Label=LED1
PB15.Signal=GPIO_Output
PB9.GPIO_Label=LED2
PB9.Signal=GPIO_Output
PC14-OSC32_IN.Signal=RCC_OSC32_IN
PC15-OSC32_OUT.Signal=RCC_OSC32_OUT
PC3.GPIO_Label=RF_CTRL3
PC3.Signal=GPIO_Output
PC4.GPIO_Label=RF_CTRL1
PC4.Signal=GPIO_Output
PC5.GPIO_Label=RF_CTRL2
PC5.Signal=GPIO_Output
PC6.GPIO_Label=BUT3
PC6.Signal=GPXTI6

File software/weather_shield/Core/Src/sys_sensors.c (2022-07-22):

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

/* Includes ------------------------------------------------------------------*/
#include "stdint.h"
#include "stm32l4xx_hal.h"
#include "math.h"
#include "main.h"
//#include "sys_conf.h"
//#include "sys_app.h"
#include "sys_sensors.h"
//#include "utilities_conf.h"
#include "stdio.h"
#include "string.h"
#include <stdlib.h>
#define SENSOR_ENABLED              0
#define COEFF_A  0.000854942
#define COEFF_B  0.000257305
#define COEFF_C  0.000000165368

/* USER CODE BEGIN Includes */
#if defined (SENSOR_ENABLED) && (SENSOR_ENABLED == 1)
#if defined (X_NUCLEO_IKS01A2)
#warning "IKS drivers are today available for several families but not stm32WL"
#warning "up to the user adapt IKS low layer to map it on WL board driver"
#warning "this code would work only if user provide necessary IKS and BSP layers"
#include "iks01a2_env_sensors.h"
#elif defined (X_NUCLEO_IKS01A3)
#include "main.h"
#include "bme680.h"
#include "gas_sensor.h"
/*
## How to add IKS01A3 to CubeWL

 1. Download STM32CubeExpansion_MEMS1_V8.0.0
 2. Copy Drivers From `STM32CubeExpansion_MEMS1_V8.0.0\Drivers\BSP\IKS01A3` to CubeWL `Drivers\BSP\IKS01A3` and add to the IDE Project
 3. Copy `STM32CubeExpansion_MEMS1_V8.0.0\Drivers\BSP\IKS01A3\iks01a3_conf_template.h` into `Projects\NUCLEO-WL55JC\Applications\LoRaWAN\End_Node\LoRaWAN\Target\iks01a3_conf.h`.
 4. Copy files nucleo_l476rg_bus.c/nucleo_l476rg_bus.h  from `STM32L476RG-Nucleo\Applications\IKS01A3\ActiveTime\Inc and \Src` to `Projects\NUCLEO-WL55JC\Applications\LoRaWAN\End_Node\LoRaWAN\Target` and rename to `nucleo_wl55jc_bus.c` and `nucleo_wl55jc_bus.h` respectively
 5. Update `nucleo_wl55jc_bus.c`  include files  to
 ```bash
#include "nucleo_wl55jc_bus.h"
#include "stm32wlxx_nucleo_errno.h"
#include "stm32wlxx_hal.h"
```

6. Update definitions in `nucleo_wl55jc_bus.h`(to be commented since already defined elsewhere)

 ```bash
//#define USE_HAL_SPI_REGISTER_CALLBACKS 0
//#define USE_HAL_I2C_REGISTER_CALLBACKS 0
```

7. copy following components and add them (.c and .h) into IDE Project

../../../../../../Drivers/BSP/Components/lsm6dso
../../../../../../Drivers/BSP/Components/lis2dw12
../../../../../../Drivers/BSP/Components/lis2mdl
../../../../../../Drivers/BSP/Components/hts221
../../../../../../Drivers/BSP/Components/lps22hh
../../../../../../Drivers/BSP/Components/stts751
../../../../../../Drivers/BSP/Components/Common

8. Enable #define HAL_I2C_MODULE_ENABLED in stm32_hal_conf.h
9. Add stm32wlxx_hal_i2c.c and stm32wlxx_hal_i2c_ex.c in the IDE Project
10. Update hi2c->Instance in `nucleo_wl55jc_bus.c` to

```bash
  hi2c->Instance = I2C2;
```

11. Update msp function in `nucleo_wl55jc_bus.c`

```bash
static void I2C2_MspInit(I2C_HandleTypeDef *i2cHandle)
{
  GPIO_InitTypeDef GPIO_InitStruct;

  GPIO_InitStruct.Pin = GPIO_PIN_11 | GPIO_PIN_12;
  GPIO_InitStruct.Mode = GPIO_MODE_AF_OD;
  GPIO_InitStruct.Pull = GPIO_PULLUP;
  GPIO_InitStruct.Speed = GPIO_SPEED_FREQ_VERY_HIGH;
  GPIO_InitStruct.Alternate = GPIO_AF4_I2C2;
  HAL_GPIO_Init(GPIOA, &GPIO_InitStruct);

  __HAL_RCC_I2C2_CLK_ENABLE();
}

static void I2C2_MspDeInit(I2C_HandleTypeDef *i2cHandle)
{
  __HAL_RCC_I2C2_CLK_DISABLE();

  HAL_GPIO_DeInit(GPIOA, GPIO_PIN_11 | GPIO_PIN_12);

}
```
12. Replace I2C1xx by MX_I2C2xx and i2c1 by i2c2 in `nucleo_wl55jc_bus.c`
13. Replace I2C1xx by MX_I2C2xx in `nucleo_wl55jc_bus.h`
 */
#warning "IKS drivers are today available for several families but not stm32WL, follow steps defined in sys_sensors.c"
#include "iks01a3_env_sensors.h"
#else  /* not X_IKS01xx */
#error "user to include its sensor drivers"
#endif  /* X_NUCLEO_IKS01xx */
#elif !defined (SENSOR_ENABLED)
#error SENSOR_ENABLED not defined
#endif  /* SENSOR_ENABLED */
/* USER CODE END Includes */

/* External variables ---------------------------------------------------------*/

/* USER CODE BEGIN PD */
#define STSOP_LATTITUDE           ((float) 43.618622 )  /*!< default latitude position */
#define STSOP_LONGITUDE           ((float) 7.051415  )  /*!< default longitude position */
#define MAX_GPS_POS               ((int32_t) 8388607 )  /*!< 2^23 - 1 */
#define HUMIDITY_DEFAULT_VAL      50.0f                 /*!< default humidity */
#define TEMPERATURE_DEFAULT_VAL   18.0f                 /*!< default temperature */
#define PRESSURE_DEFAULT_VAL      1000.0f               /*!< default pressure */
/* USER CODE END PD */
extern uint8_t rcvbuff[64];
extern uint8_t command[64];
extern uint8_t rcvptr;

/* USER CODE BEGIN PV */
#if defined (SENSOR_ENABLED) && (SENSOR_ENABLED == 1)
#if defined (X_NUCLEO_IKS01A2)
#warning "IKS drivers are today available for several families but not stm32WL"
#warning "up to the user adapt IKS low layer to map it on WL board driver"
#warning "this code would work only if user provide necessary IKS and BSP layers"
IKS01A2_ENV_SENSOR_Capabilities_t EnvCapabilities;
#elif defined (X_NUCLEO_IKS01A3)
IKS01A3_ENV_SENSOR_Capabilities_t EnvCapabilities;
#else  /* not X_IKS01Ax */
#error "user to include its sensor drivers"
#endif  /* X_NUCLEO_IKS01 */
#elif !defined (SENSOR_ENABLED)
#error SENSOR_ENABLED not defined
#endif  /* SENSOR_ENABLED */


extern  bme_gas_sensor;
/* USER CODE END PV */

/* Exported functions --------------------------------------------------------*/
int32_t  EnvSensors_Read(sensor_t *sensor_data)
{
	/* USER CODE BEGIN EnvSensors_Read */
	float HUMIDITY_Value = HUMIDITY_DEFAULT_VAL;
	float TEMPERATURE_Value = TEMPERATURE_DEFAULT_VAL;
	float PRESSURE_Value = PRESSURE_DEFAULT_VAL;

#if defined (SENSOR_ENABLED) && (SENSOR_ENABLED == 1)
#if (USE_IKS01A2_ENV_SENSOR_HTS221_0 == 1)
	IKS01A2_ENV_SENSOR_GetValue(HTS221_0, ENV_HUMIDITY, &HUMIDITY_Value);
	IKS01A2_ENV_SENSOR_GetValue(HTS221_0, ENV_TEMPERATURE, &TEMPERATURE_Value);
#endif /* USE_IKS01A2_ENV_SENSOR_HTS221_0 */
#if (USE_IKS01A2_ENV_SENSOR_LPS22HB_0 == 1)
	IKS01A2_ENV_SENSOR_GetValue(LPS22HB_0, ENV_PRESSURE, &PRESSURE_Value);
	IKS01A2_ENV_SENSOR_GetValue(LPS22HB_0, ENV_TEMPERATURE, &TEMPERATURE_Value);
#endif /* USE_IKS01A2_ENV_SENSOR_LPS22HB_0 */
#if (USE_IKS01A3_ENV_SENSOR_HTS221_0 == 1)
	IKS01A3_ENV_SENSOR_GetValue(IKS01A3_HTS221_0, ENV_HUMIDITY, &HUMIDITY_Value);
	IKS01A3_ENV_SENSOR_GetValue(IKS01A3_HTS221_0, ENV_TEMPERATURE, &TEMPERATURE_Value);
#endif /* USE_IKS01A3_ENV_SENSOR_HTS221_0 */
#if (USE_IKS01A3_ENV_SENSOR_LPS22HH_0 == 1)
	IKS01A3_ENV_SENSOR_GetValue(IKS01A3_LPS22HH_0, ENV_PRESSURE, &PRESSURE_Value);
	IKS01A3_ENV_SENSOR_GetValue(IKS01A3_LPS22HH_0, ENV_TEMPERATURE, &TEMPERATURE_Value);
#endif /* USE_IKS01A3_ENV_SENSOR_LPS22HH_0 */
#elif !defined (SENSOR_ENABLED)
#error SENSOR_ENABLED not defined
#endif  /* SENSOR_ENABLED */

	sensor_data->humidity    = HUMIDITY_Value;
	sensor_data->temperature = TEMPERATURE_Value;
	sensor_data->pressure    = PRESSURE_Value;

	sensor_data->latitude  = (int32_t)((STSOP_LATTITUDE  * MAX_GPS_POS) / 90);
	sensor_data->longitude = (int32_t)((STSOP_LONGITUDE  * MAX_GPS_POS) / 180);
	return 0;
	/* USER CODE END EnvSensors_Read */
}
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

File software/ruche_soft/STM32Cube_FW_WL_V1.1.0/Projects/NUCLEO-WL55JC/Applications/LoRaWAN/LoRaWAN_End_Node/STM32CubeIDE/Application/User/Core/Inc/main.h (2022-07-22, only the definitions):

#define RTC_N_PREDIV_S 10
#define RTC_PREDIV_S ((1<<RTC_N_PREDIV_S)-1)
#define RTC_PREDIV_A ((1<<(15-RTC_N_PREDIV_S))-1)
#define LED1_Pin GPIO_PIN_15
#define LED1_GPIO_Port GPIOB
#define LED2_Pin GPIO_PIN_9
#define LED2_GPIO_Port GPIOB
#define PROB3_Pin GPIO_PIN_14
#define PROB3_GPIO_Port GPIOB
#define RF_CTRL3_Pin GPIO_PIN_3
#define RF_CTRL3_GPIO_Port GPIOC
#define BUT1_Pin GPIO_PIN_0
#define BUT1_GPIO_Port GPIOA
#define BUT1_EXTI_IRQn EXTI0_IRQn
#define PROB2_Pin GPIO_PIN_13
#define PROB2_GPIO_Port GPIOB
#define RF_CTRL2_Pin GPIO_PIN_5
#define RF_CTRL2_GPIO_Port GPIOC
#define PROB1_Pin GPIO_PIN_12
#define PROB1_GPIO_Port GPIOB
#define RF_CTRL1_Pin GPIO_PIN_4
#define RF_CTRL1_GPIO_Port GPIOC
#define BUT3_Pin GPIO_PIN_6
#define BUT3_GPIO_Port GPIOC
#define BUT2_Pin GPIO_PIN_1
#define BUT2_GPIO_Port GPIOA
#define BUT2_EXTI_IRQn EXTI1_IRQn
#define OPTO_Pin GPIO_PIN_3
#define OPTO_GPIO_Port GPIOA
#define USARTx_RX_Pin GPIO_PIN_3
#define USARTx_RX_GPIO_Port GPIOA
#define USARTx_TX_Pin GPIO_PIN_2
#define USARTx_TX_GPIO_Port GPIOA
#define PROB4_Pin GPIO_PIN_10
#define PROB4_GPIO_Port GPIOB

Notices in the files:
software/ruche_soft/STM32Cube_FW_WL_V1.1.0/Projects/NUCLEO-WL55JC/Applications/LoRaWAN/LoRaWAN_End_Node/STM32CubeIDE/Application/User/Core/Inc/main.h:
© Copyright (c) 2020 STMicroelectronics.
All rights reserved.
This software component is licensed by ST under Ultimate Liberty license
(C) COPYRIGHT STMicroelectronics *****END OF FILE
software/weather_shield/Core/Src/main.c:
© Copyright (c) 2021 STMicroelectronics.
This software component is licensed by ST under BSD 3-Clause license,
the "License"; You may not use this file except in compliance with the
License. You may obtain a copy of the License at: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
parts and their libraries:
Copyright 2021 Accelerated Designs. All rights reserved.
